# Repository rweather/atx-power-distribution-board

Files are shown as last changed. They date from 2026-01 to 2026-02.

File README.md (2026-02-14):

ATX Power Distribution Board
============================

This repository contains a design for an adapter board that connects
to a standard 24-pin ATX power supply connector and makes the
voltage rails available for homebrew computer use.

The board is designed to be retrofitted into an ITX computer case,
with the ITX power button, power LED, hdd LED, and reset button
connected to the board to provide power on/off control.

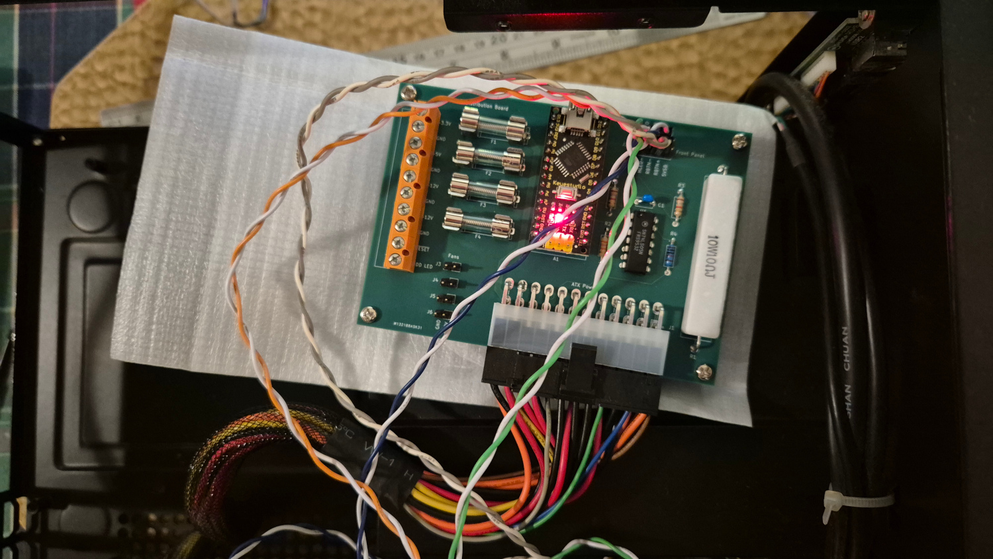
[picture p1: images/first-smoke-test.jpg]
ATX Power Distribution Board


* [Schematic](schematics/ATX-Power-Distribution-Board/PDF/ATX-Power-Distribution-Board.pdf)

## License

Distributed under the terms of the MIT license.

## Contact

For more information on this code, to report bugs, or to suggest
improvements, please contact the author Rhys Weatherley via
[email](mailto:rhys.weatherley@gmail.com).

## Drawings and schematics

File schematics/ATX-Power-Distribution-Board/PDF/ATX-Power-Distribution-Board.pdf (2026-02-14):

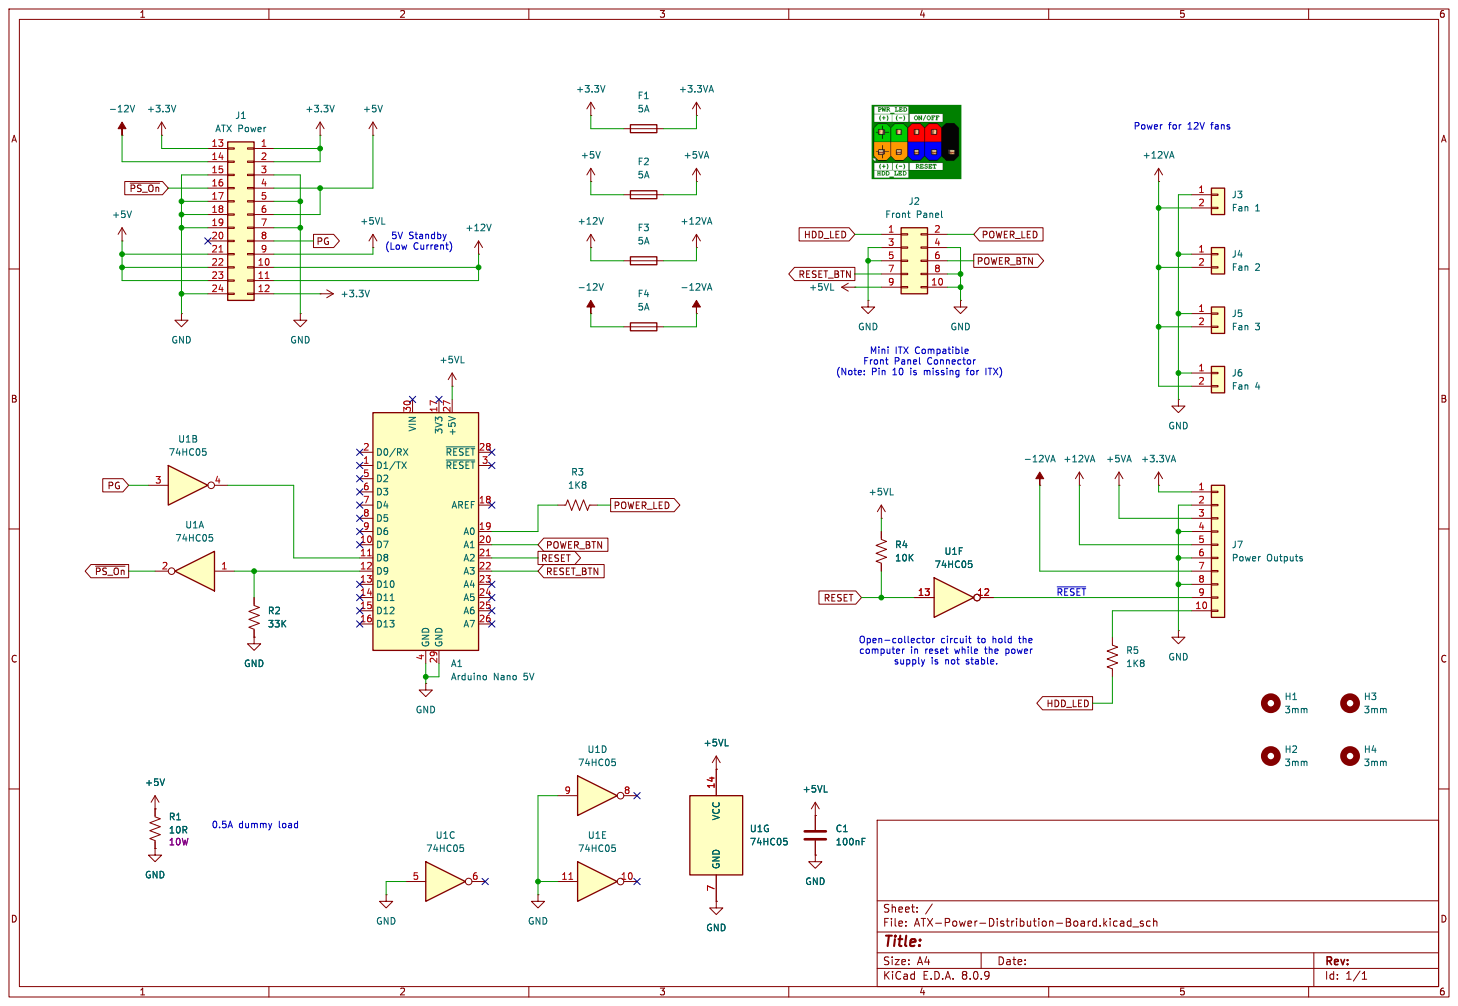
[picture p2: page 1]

Id: 1/1 Title: File: ATX-Power-Distribution-Board.kicad_sch Sheet: /

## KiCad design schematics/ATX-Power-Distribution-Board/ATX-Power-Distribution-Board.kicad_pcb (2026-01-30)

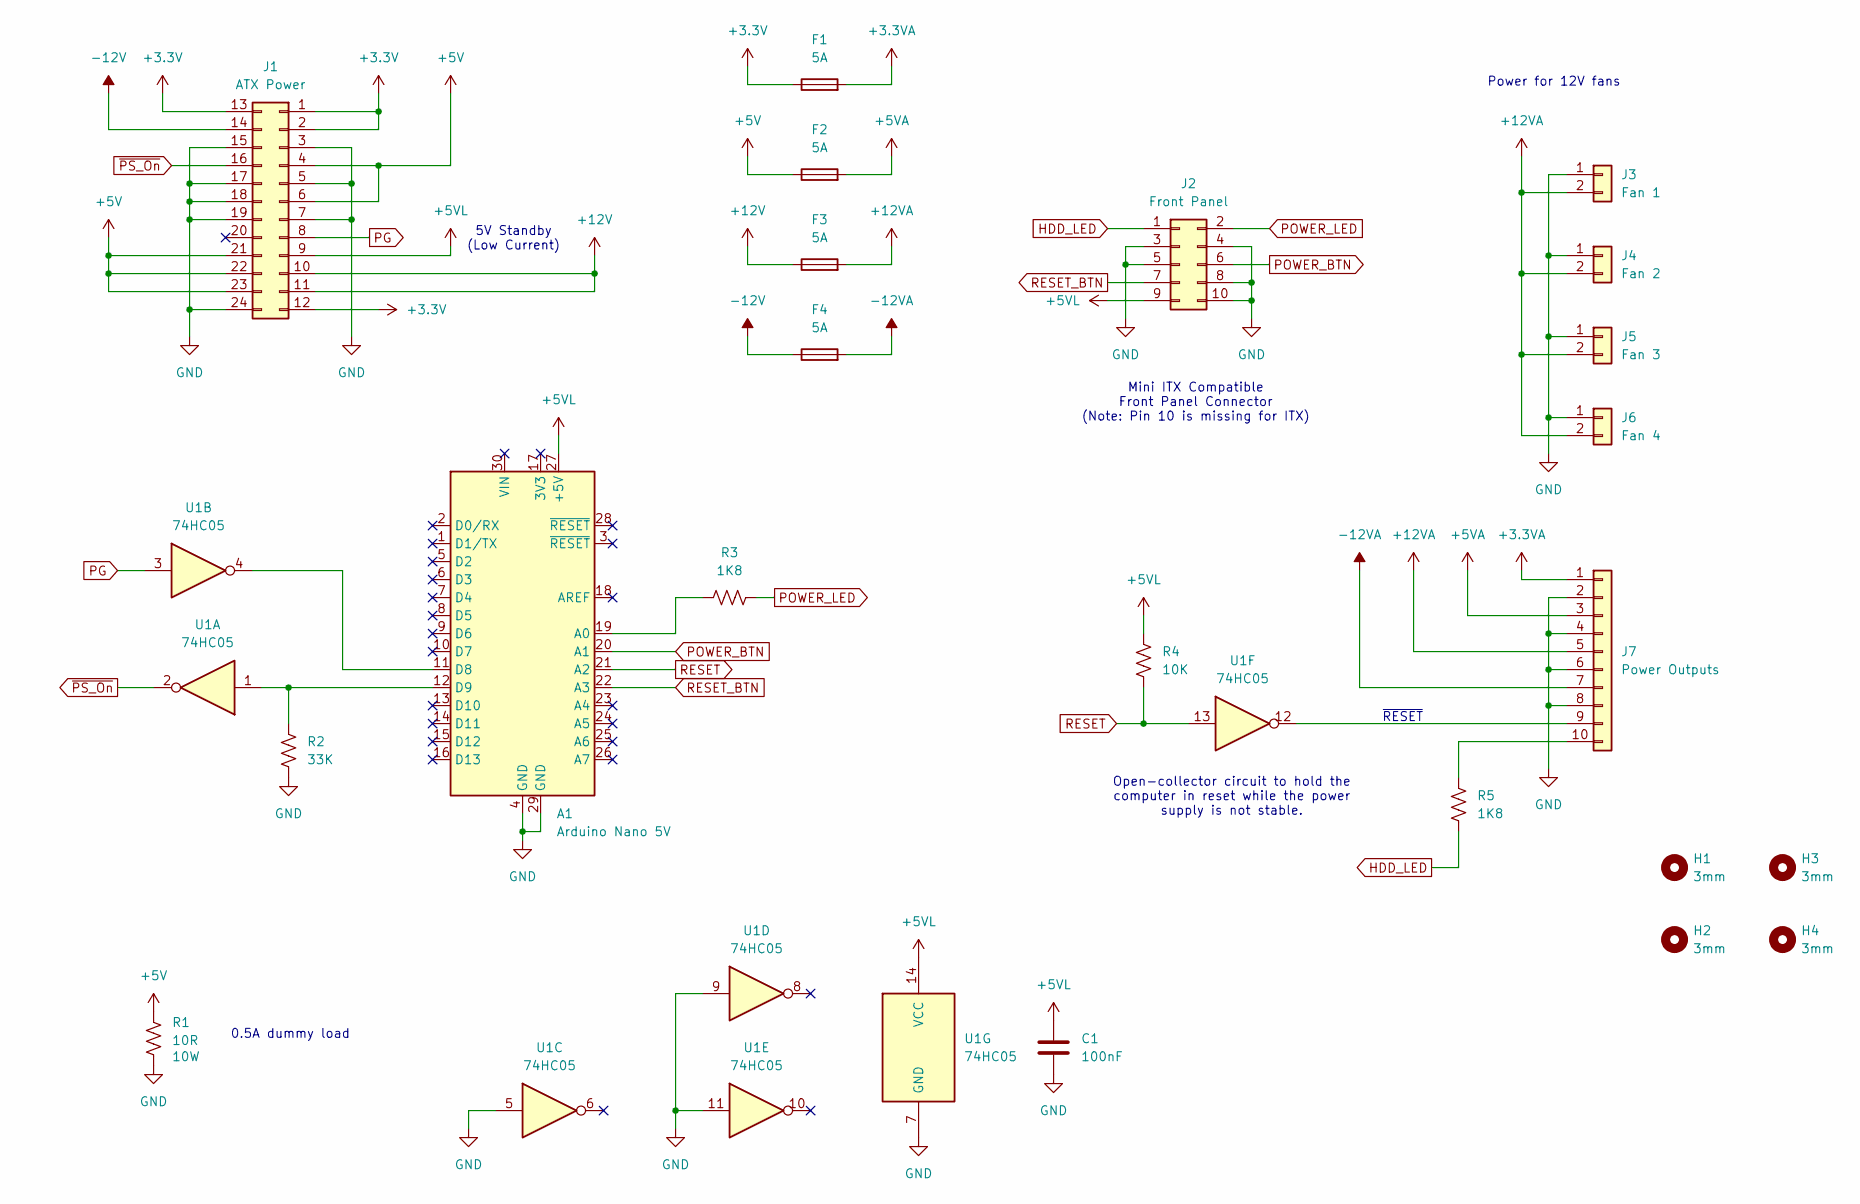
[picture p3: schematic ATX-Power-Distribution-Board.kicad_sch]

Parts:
A1: Arduino Nano 5V; Arduino_Nano
C1: 100nF; C_Disc_D5.0mm_W2.5mm_P5.00mm
F1, F2, F3, F4: 5A; Fuseholder_Clip-5x20mm_Littelfuse_111_Inline_P20.00x5.00mm_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
H1, H2, H3, H4: 3mm; MountingHole_3mm
J1: ATX Power; Molex_Mini-Fit_Jr_5569-24A2_2x12_P4.20mm_Horizontal
J2: Front Panel; PinHeader_2x05_P2.54mm_Vertical
J3: Fan 1; PinHeader_1x02_P2.54mm_Vertical
J4: Fan 2; PinHeader_1x02_P2.54mm_Vertical
J5: Fan 3; PinHeader_1x02_P2.54mm_Vertical
J6: Fan 4; PinHeader_1x02_P2.54mm_Vertical
J7: Power Outputs; PhoenixContact_MC_1,5_10-G-5.08_1x10_P5.08mm_Horizontal
R1: 10R; R_Axial_Power_L50.0mm_W9.0mm_P55.88mm; Rating 10W
R2: 33K; R_Axial_DIN0207_L6.3mm_D2.5mm_P10.16mm_Horizontal
R3, R5: 1K8; R_Axial_DIN0207_L6.3mm_D2.5mm_P10.16mm_Horizontal
R4: 10K; R_Axial_DIN0207_L6.3mm_D2.5mm_P10.16mm_Horizontal
U1: 74HC05; DIP-14_W7.62mm

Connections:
+3.3V: F1.1, J1.1, J1.2, J1.12, J1.13
+3.3VA: F1.2, J7.1
+5V: F2.1, J1.4, J1.6, J1.21, J1.22, J1.23, R1.1
+5VA: F2.2, J7.3
+5VL: A1.27 (+5V), C1.1, J1.9, J2.9, R4.1, U1.14 (VCC)
+12V: F3.1, J1.10, J1.11
+12VA: F3.2, J3.2, J4.2, J5.2, J6.2, J7.5
-12V: F4.1, J1.14
-12VA: F4.2, J7.7
GND: A1.4 (GND), A1.29 (GND), C1.2, J1.3, J1.5, J1.7, J1.15, J1.17, J1.18, J1.19, J1.24, J2.3, J2.4, J2.5, J2.8, J2.10, J3.1, J4.1, J5.1, J6.1, J7.2, J7.4, J7.6, J7.8, R1.2, R2.2, U1.5, U1.7 (GND), U1.9, U1.11
HDD_LED: J2.1, R5.2
unnamed: A1.19 (A0), R3.1
unnamed: A1.11 (D8), U1.4
unnamed: A1.12 (D9), R2.1, U1.1
unnamed: J7.9, U1.12
unnamed: J7.10, R5.1
PG: J1.8, U1.3
POWER_BTN: A1.20 (A1), J2.6
POWER_LED: J2.2, R3.2
RESET: A1.21 (A2), R4.2, U1.13
RESET_BTN: A1.22 (A3), J2.7
~PS_On: J1.16, U1.2

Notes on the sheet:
Mini ITX Compatible Front Panel Connector (Note: Pin 10 is missing for ITX)
Power for 12V fans
0.5A dummy load
~{RESET}
5V Standby (Low Current)
Open-collector circuit to hold the computer in reset while the power supply is not stable.

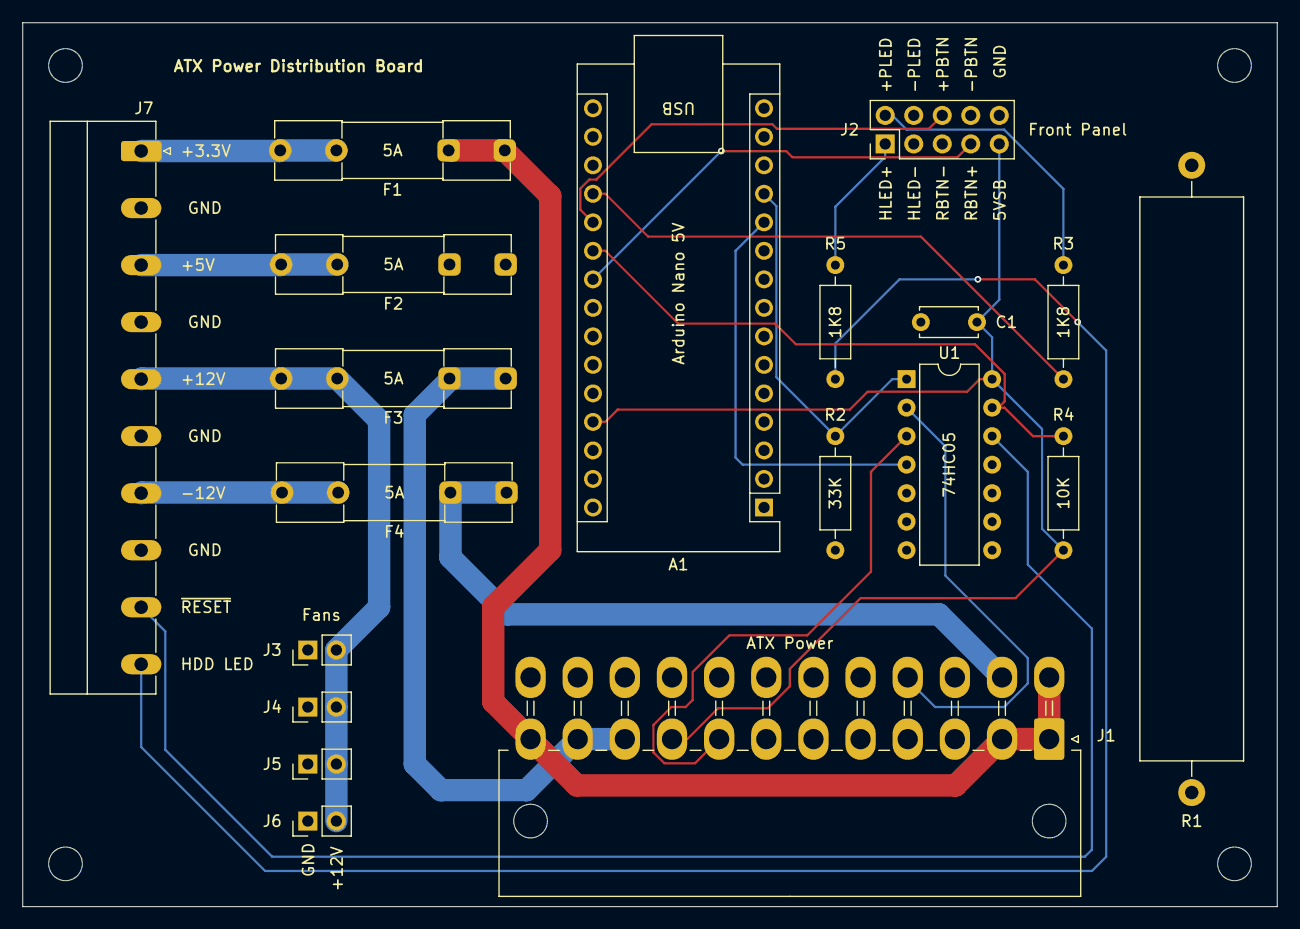
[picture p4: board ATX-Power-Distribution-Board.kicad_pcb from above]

Board: 4 copper layers, 111.8 x 78.7 mm, 23 parts (0 on the bottom side), 22 nets.

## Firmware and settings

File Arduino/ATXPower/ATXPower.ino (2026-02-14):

/*
 * Copyright (C) 2026 Rhys Weatherley
 *
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
 * THE SOFTWARE IS PROVIDED "AS IS", WITHOUT WARRANTY OF ANY KIND, EXPRESS
 * OR IMPLIED, INCLUDING BUT NOT LIMITED TO THE WARRANTIES OF MERCHANTABILITY,
 * FITNESS FOR A PARTICULAR PURPOSE AND NONINFRINGEMENT. IN NO EVENT SHALL THE
 * AUTHORS OR COPYRIGHT HOLDERS BE LIABLE FOR ANY CLAIM, DAMAGES OR OTHER
 * LIABILITY, WHETHER IN AN ACTION OF CONTRACT, TORT OR OTHERWISE, ARISING
 * FROM, OUT OF OR IN CONNECTION WITH THE SOFTWARE OR THE USE OR OTHER
 * DEALINGS IN THE SOFTWARE.
 */

// Pin assignment.
#define STATUS_LED  13      // Status LED on the Arduino.
#define POWER_LED   A0      // Output, active-high, turn on the power LED.
#define POWER_BTN   A1      // Input, active-low, power button.
#define RESET_CTRL  A2      // Output, active-high, hold computer in reset.
#define RESET_BTN   A3      // Input, active-low, reset button.
#define POWER_GOOD  8       // Input, active-low, power supply is good.
#define POWER_ON    9       // Output, active-high, turn on power supply.

// Debounce timeouts for the power button, in milliseconds.
#define POWER_BTN_ON_TIME   100     // Press for 100ms to turn the system on.
#define POWER_BTN_OFF_TIME  1000    // Hold for 1s to turn the system off.

// Minimum time to hold the computer in reset when reset button pressed.
#define RESET_TIME          500

// Time to wait for the power good signal to go high before concluding
// that the power supply is not working correctly.
#define POWER_UP_TIME       5000

// States for the state machine.
typedef enum
{
    STATE_OFF,          // Computer is turned off.
    STATE_WAIT_ON,      // Power button pressed to turn on, wait for release.
    STATE_POWERING_UP,  // Power supply is turning on, computer held in reset.
    STATE_NORMAL,       // Computer is running normally.
    STATE_WAIT_OFF,     // Power button pressed to turn off, wait for release.
    STATE_WAIT_OFF2,    // Second stage power off, wait to lower reset line.
    STATE_WAIT_RESET,   // Reset button is pressed, wait for release.
    STATE_RESET         // Reset the computer due to the reset button.

} State_t;

State_t state = STATE_OFF;

class ButtonDebouncer
{
public:
    ButtonDebouncer(int pin);

    void run();
    bool isPressed() const { return pressed; }
    void setTimeout(unsigned long ms) { timeout = ms; }

private:
    int pinnum;
    bool rawPressed;
    bool pressed;
    bool timerRunning;
    unsigned long timer;
    unsigned long timeout;
};

ButtonDebouncer::ButtonDebouncer(int pin)
    : pinnum(pin)
    , rawPressed(false)
    , pressed(false)
    , timerRunning(false)
    , timer(0)
    , timeout(50)
{
}

void ButtonDebouncer::run()
{
    bool nowPressed = (digitalRead(pinnum) == LOW);
    if (nowPressed != rawPressed) {
        // Change in the raw state of the button.  Restart the timer.
        timer = millis();
        timerRunning = true;
        rawPressed = nowPressed;
    } else if (timerRunning) {
        if ((millis() - timer) >= timeout) {
            // Debounce time has elapsed.  Update the pressed state.
            pressed = nowPressed;
            timerRunning = false;
        }
    }
}

ButtonDebouncer powerButton(POWER_BTN);
ButtonDebouncer resetButton(RESET_BTN);
ButtonDebouncer powerGood(POWER_GOOD);

void setup()
{
    // Initialise the outputs.
    digitalWrite(POWER_LED, LOW);   // Power LED is off at startup.
    digitalWrite(STATUS_LED, LOW);
    digitalWrite(RESET_CTRL, HIGH); // Hold the computer in reset for now.
    digitalWrite(POWER_ON, LOW);    // Don't turn on the power supply yet.

    // Configure all pins to the desired modes.
    pinMode(STATUS_LED, OUTPUT);
    pinMode(POWER_LED, OUTPUT);
    pinMode(POWER_BTN, INPUT_PULLUP);
    pinMode(RESET_CTRL, OUTPUT);
    pinMode(RESET_BTN, INPUT_PULLUP);
    pinMode(POWER_GOOD, INPUT_PULLUP);
    pinMode(POWER_ON, OUTPUT);

    // Currently in the off state, waiting for the power button to be pressed.
    state = STATE_OFF;
    powerButton.setTimeout(POWER_BTN_ON_TIME);
}

// Shut down the computer immediately.
void shutdown(bool withReset = true)
{
    if (withReset) {
        digitalWrite(RESET_CTRL, HIGH);
    }
    digitalWrite(POWER_ON, LOW);
    digitalWrite(POWER_LED, LOW);
    digitalWrite(STATUS_LED, LOW);
    powerButton.setTimeout(POWER_BTN_ON_TIME);
}

static unsigned long global_timer = 0;
static unsigned long global_timeout = 0;

void startTimeout(unsigned long ms)
{
    global_timer = millis();
    global_timeout = ms;
}

bool isTimedOut()
{
    return (millis() - global_timer) >= global_timeout;
}

void loop()
{
    // Debounce the current state of the inputs.
    powerButton.run();
    resetButton.run();
    powerGood.run();

    // Run the state machine.
    switch (state) {
    case STATE_OFF:
        // Wait for the user to press the power button.
        if (powerButton.isPressed()) {
            state = STATE_WAIT_ON;
        }
        break;

    case STATE_WAIT_ON:
        // Wait for the user to release the power button.
        if (!powerButton.isPressed()) {
            // Turn on the supply, while still holding the computer in reset.
            digitalWrite(POWER_ON, HIGH);
            digitalWrite(POWER_LED, HIGH);
            digitalWrite(STATUS_LED, HIGH);
            powerButton.setTimeout(POWER_BTN_OFF_TIME);
            startTimeout(POWER_UP_TIME);
            state = STATE_POWERING_UP;
        }
        break;

    case STATE_POWERING_UP:
        // Power supply is on, waiting for the power good signal.
        if (powerGood.isPressed()) {
            // Hold the computer in reset for a little longer.
            startTimeout(RESET_TIME);
            state = STATE_RESET;
        } else if (isTimedOut()) {
            // Took too long for power good to come up.  Something went wrong.
            shutdown();
            state = STATE_OFF;
        }
        break;

    case STATE_NORMAL:
        // Normal operations.
        if (powerButton.isPressed()) {
            // User turned the power off.  Shut everything down except reset.
            shutdown(false);
            powerButton.setTimeout(POWER_BTN_ON_TIME);
            state = STATE_WAIT_OFF;
        } else if (resetButton.isPressed()) {
            // Explicit request to reset the attached computer.
            digitalWrite(RESET_CTRL, HIGH);
            state = STATE_WAIT_RESET;
        } else if (!powerGood.isPressed()) {
            // Power good signal from the power supply has gone away.
            // Shut the computer down immediately.
            shutdown();
            state = STATE_OFF;
        }
        break;

    case STATE_WAIT_OFF:
        // Wait for the power button to be released in the off state.
        if (!powerButton.isPressed()) {
            state = STATE_WAIT_OFF2;
            startTimeout(RESET_TIME);
        }
        break;

    case STATE_WAIT_OFF2:
        // After the timeout, forcibly reset the computer and stop.
        // It should have already lost power by now.
        if (isTimedOut()) {
            digitalWrite(RESET_CTRL, HIGH);
            state = STATE_OFF;
        }
        break;

    case STATE_WAIT_RESET:
        // Wait for the reset button to be released.
        if (!resetButton.isPressed()) {
            // Hold the computer in reset for a little longer after release.
            startTimeout(RESET_TIME);
            state = STATE_RESET;
        }
        break;

    case STATE_RESET:
        // Time to release the computer from reset?
        if (isTimedOut()) {
            digitalWrite(RESET_CTRL, LOW);
            state = STATE_NORMAL;
        }
        break;
    }
}

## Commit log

2026-01-30 Schematic for ATX power distribution board
    [ATX-Power-Distribution-Board-B_Cu.gbl, ATX-Power-Distribution-Board-B_Mask.gbs, ATX-Power-Distribution-Board-B_Paste.gbp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]
2026-02-07 Arduino sketch to control the power supply
2026-02-14 Update PDF schematic
2026-02-14 Control the power LED from the Arduino sketch
